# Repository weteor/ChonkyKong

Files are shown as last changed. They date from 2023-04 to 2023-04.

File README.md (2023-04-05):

### Kong

48 key orthogonal keyboard with offset bottom row

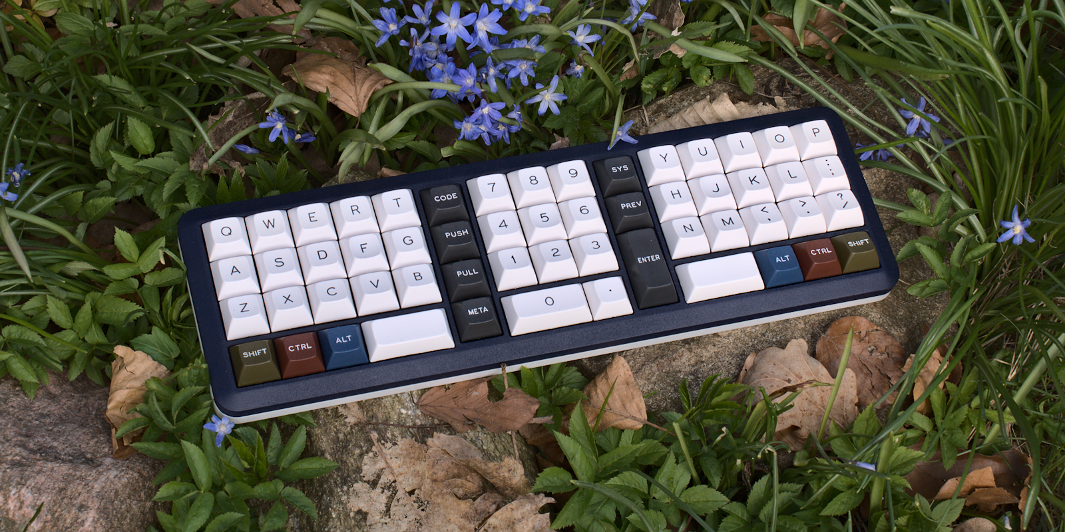
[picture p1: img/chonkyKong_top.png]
top


## Features

- Hotswap sockets
- onboard rp2040
- production files for pcba
- case files are supplied (stl, dxf, as well as the freecad files)
- QMK with vial support
- completely open source, permissive license ([CERN-OHL-P](https://cern-ohl.web.cern.ch/home))

- bottom rows supported:
  - alpha thumbs
    - 1u 1u 1u
    - 2u 1u
    - 3u
  - numpad thumbs
    - 1u 1u 1u
    - 2u 1u
    - 1u 2u
  - makro cols
    - 1u 1u 1u 1u
    - 2u 1u 1u
    - 1u 1u 2u
    - 1u 2u 1u
    - 2u 2u

## Want one?

All production files you need to build your own board can be found here: [pcb](./prod/pcb) / [case](./prod/case).

Parts needed beside the assembled pcbs:

- up to 60 hotswap sockets ( mx or choc)

- up to 60 of your favourite switches (mx or choc)

- 8 m2 heat inserts

- 8 m2 screws

### firmware
The first time the pcb is plugged in, the bootloader will provide a drive to upload the firmware file. 
You may either build the firmware yourself or use the provided vial firmware files [here](./firmware). You may use VIAL ([download](https://get.vial.today/) to program your board after that, without need to build a new firmware.

### the rest

Everything in this repository is free to use however you might see fit. If you want to support me and my projects, please consider linking back to this repository if you build/change/use anything.

If you would like to send me a tip, you could do it [here](https://ko-fi.com/weteor) (Please don't feel like you have to).

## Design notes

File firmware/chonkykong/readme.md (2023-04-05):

# 3W6

3W6_rev2
3W6_rev2

The 3w6 is a low profile, split ortholinear keyboard with 36 keys.

* Rev2: 
  - onboard microcontroller (ATMega32U4)
  - USB-C connector Board <-> PC
  - USB-C connectors between both split halfs
  - choc spacing (18x17mm)
  - aggressive pinky stagger
  - support for Choc V1 switches
  - files for midplate (1.6 to 2mm)
  - support for [Pimoroni Trackball](https://shop.pimoroni.com/products/trackball-breakout) instead of outer thumb switch on right half, needs midplate
  - mounting holes for [Tenting Puck](https://splitkb.com/collections/keyboard-parts/products/tenting-puck), only usable without mid or switchplate

---

* Keyboard Maintainer: [weteor](https://github.com/weteor)
* Hardware Supported: 
    * 3w6 rev2 (with Pimoroni support)
* Hardware Availability: 
    * make one yourself: [Design and Productionfiles](https://github.com/weteor/3w6)
    * maintainer is selling kits when available

---
To reach the bootloader, connect the board to the PC and push the reset button on left half.

Make examples for this keyboard (after setting up your build environment):
           
    make 3w6/rev2:default
    make 3w6/rev2:default_pimoroni
   
 ---

See the [build environment setup](https://docs.qmk.fm/#/getting_started_build_tools) and the [make instructions](https://docs.qmk.fm/#/getting_started_make_guide) for more information. Brand new to QMK? Start with our [Complete Newbs Guide](https://docs.qmk.fm/#/newbs).

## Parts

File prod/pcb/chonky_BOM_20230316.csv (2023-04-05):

Comment | Designator | Footprint | LCSC
27pF | C1,C2 | Capacitor_SMD:C_0402_1005Metric | C1557
100nF | C3,C4,C5,C8,C9,C10,C11,C14 | Capacitor_SMD:C_0402_1005Metric | C307331
1uF | C6,C7,C12,C13 | Capacitor_SMD:C_0402_1005Metric | C52923
D | D1,D2,D3,D4,D5,D6,D7,D8,D9,D10,D11,D12,D13,D14,D15,D16,D17,D18,D19,D20,D21,D22,D23,D24,D25,D26,D27,D28,D29,D30,D31,D32,D33,D34,D35,D36,D37,D38,D39,D40,D41,D42,D43,D44,D45,D46,D47,D48,D49,D50,D51,D52,D53,D54,D55,D56,D57,D58,D59,D60 | weteor:D_SOD-123 | C81598
USB_C_Receptacle_USB2.0 | J2 | weteor:USB C-31-M-12 | C165948
1k | R1,R2,R5 | Resistor_SMD:R_0402_1005Metric | C11702
27R | R3,R4 | Resistor_SMD:R_0402_1005Metric | C25190
10k | R6 | Resistor_SMD:R_0402_1005Metric | C25744
5.1k | R7,R8 | Resistor_SMD:R_0402_1005Metric | C25905
RP2040 | U1 | RP2040_minimal:RP2040-QFN-56 | C2040
XC6206PxxxMR | U2 | Package_TO_SOT_SMD:SOT-23-3 | C5446
W25Q128JVS | U3 | Package_SON:SOIC-8_5.23x5.23mm_P1.27mm | C97521
USBLC6-2SC6 | U4 | Package_TO_SOT_SMD:SOT-23-6 | C2827654
Crystal_GND24_Small | Y1 | Crystal:Crystal_SMD_3225-4Pin_3.2x2.5mm | C9002

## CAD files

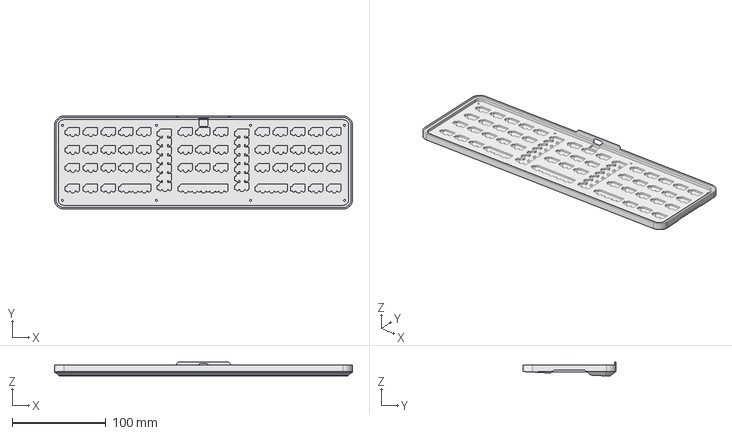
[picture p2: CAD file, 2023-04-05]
prod/case/bottom_3deg.step
317.8 x 99.2 x 15.3 mm

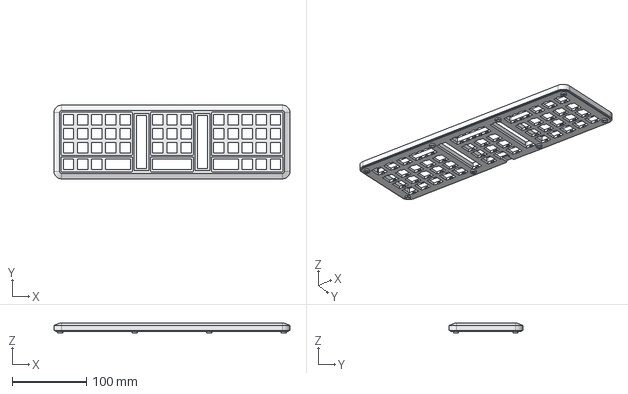
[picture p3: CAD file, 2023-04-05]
prod/case/top_3deg.step
317.8 x 99.2 x 13.0 mm

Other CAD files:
prod/case/bottom_3deg.stl
prod/case/top_3deg.stl

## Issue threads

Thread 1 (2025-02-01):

Help with component placement

OneMHz, 2025-02-01:
Sorry, but I'm a little new to this. The silk screen doesn't have identifiers for all components and I am not sure how best to convert the coordinates to locations on the physical board. I installed KiCad, but I can't figure out how to get it to show components without a lot of effort.

weteor, 2025-02-01:
Hi,

the diodes should have a directional marking on the silkscreen. For the rest of the top component please refer to this, hope that helps.

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

OneMHz, 2025-02-01:
That is perfect! Thank you

Closed 2025-02-01.

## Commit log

2023-04-05 add pcb data
    [chonky.kicad_sch]
2023-04-05 add case cad
2023-04-05 add production files pcb
    [chonky_BOM_20230316.csv, chonky_POSITION_20230316.csv]
2023-04-05 add production files case
    [bottom_3deg.step, bottom_3deg.stl, top_3deg.step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]
2023-04-05 add missing pcb file
